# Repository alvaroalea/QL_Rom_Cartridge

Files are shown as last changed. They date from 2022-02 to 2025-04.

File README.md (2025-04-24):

# QL_Rom_Cartridge
Schematic, PCB and other stuff to make ROM Cartridge for use with Sinclair QL Computer

(C) 2022 Alvaro Alea Fdz.

License under: CERN Open Hardware Licence Version 2 - Strongly Reciprocal

https://ohwr.org/cern_ohl_s_v2.txt

Remenber that when using my jerber files with JLCPCB you shall mark the option to specify the Order Number (no cost) to avoid the text JLCJLCJLCJLC in the skilscreen.
My image

## Folder: Original
This folder contain the schematic of the original Sinclair cartridge as far as i can get from pictures from internet.

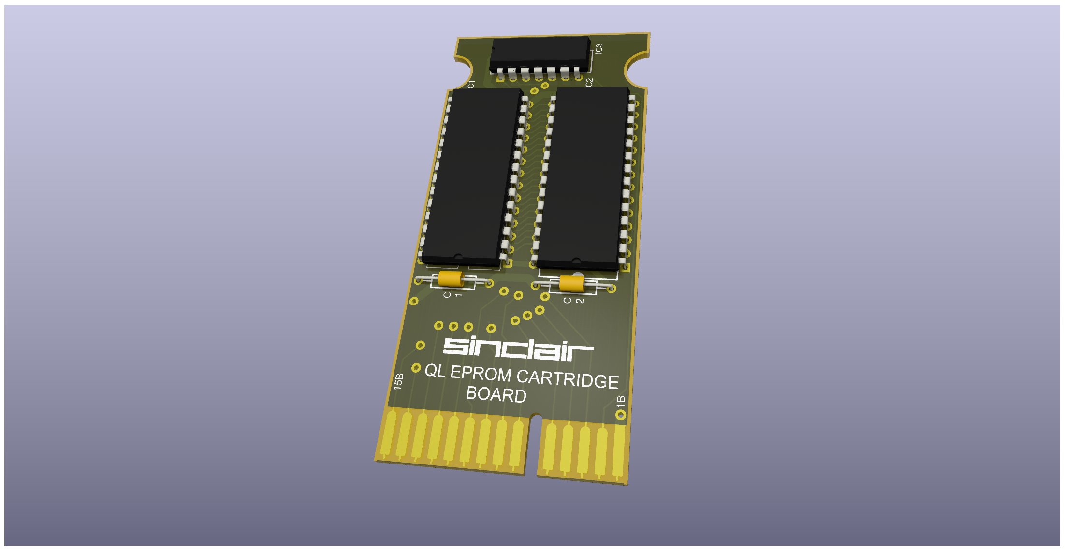
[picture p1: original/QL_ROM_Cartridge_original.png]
 

It also contains 3D pieces to do vacum form of the case

STATUS
- Schematic - Working, tested and match the original, Thank You Chr$.
- Case - Design, Non tested

## Folder: Short

### NOT TESTED, SHOULD WORK
This version need a 16Kb eprom, and is intended as a replacement of Toolkit II cartridge an others.
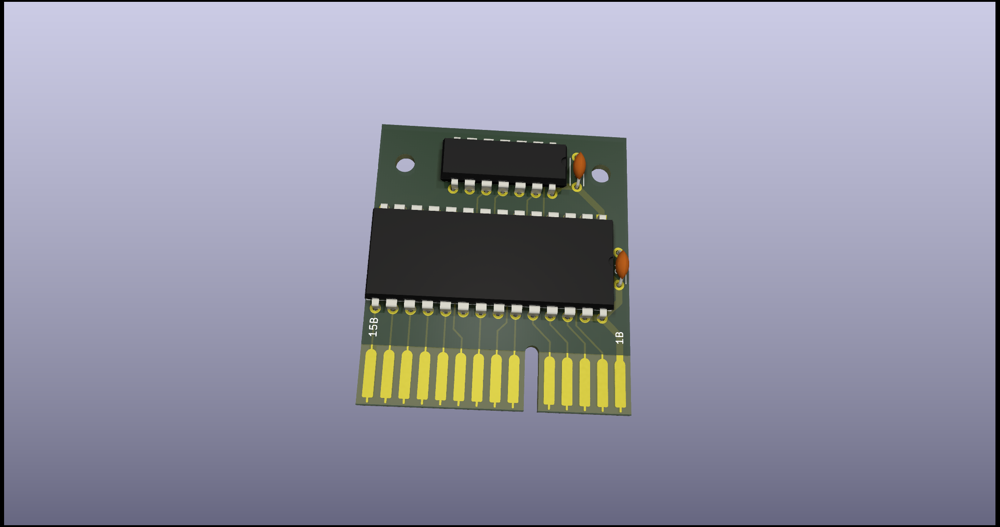
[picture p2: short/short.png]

## Folder: full_rom

### NOT TESTED, NO IDEA IF WORK
This version need a 64Kb eprom, and is intended to replace the internal ROM of the QL.

Is very important to remove the 2 ROM chips from the QL before use.

Be aware that this lock the rom cartridge, and the QL will not work without it.
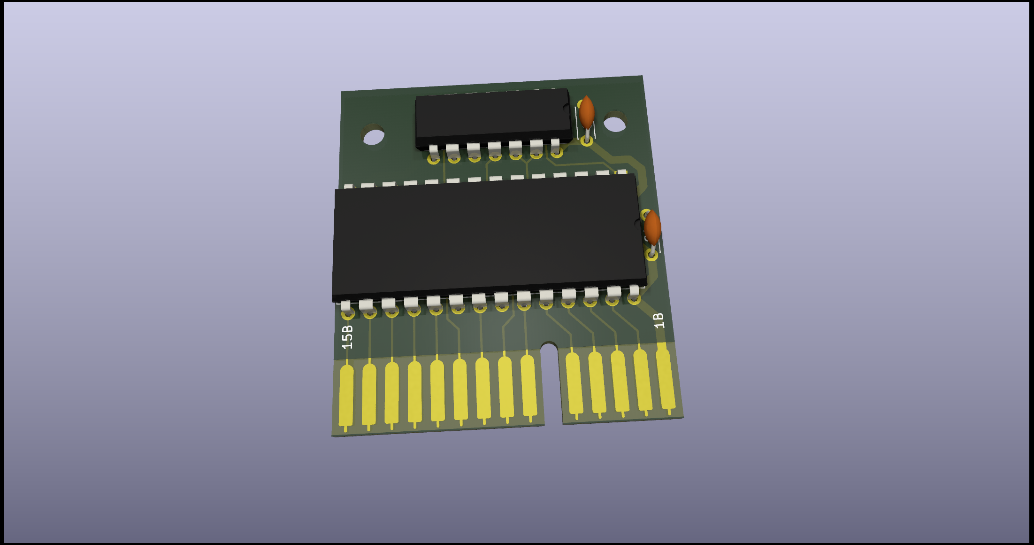
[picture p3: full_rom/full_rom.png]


## Folder: 8full_rom

### NOT TESTED, NO IDEA IF WORK
The 8full_rom is a version of full_rom with 3 switch to allow 8 diferent version of the ROM of the QL.

Is very important to remove the 2 ROM chips from the QL before use.

Be aware that this lock the rom cartridge, and the QL will not work without it.
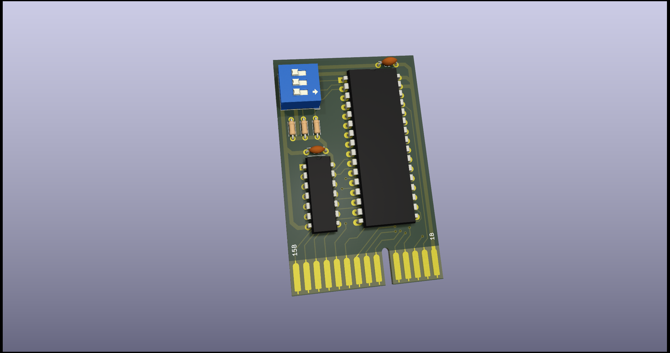
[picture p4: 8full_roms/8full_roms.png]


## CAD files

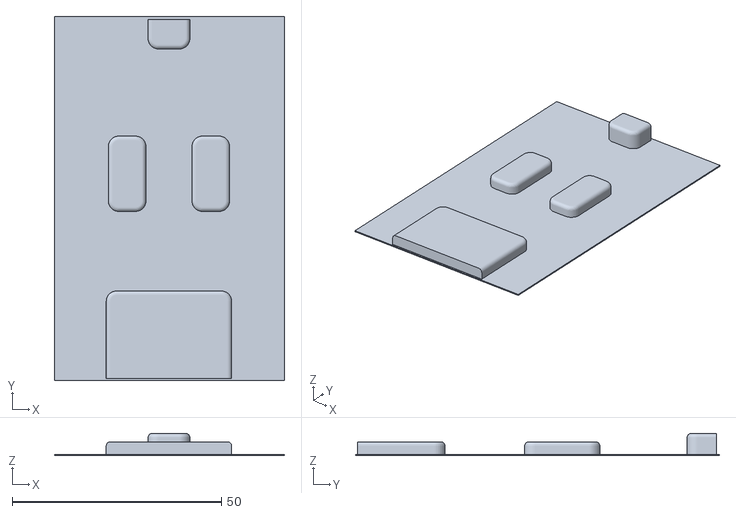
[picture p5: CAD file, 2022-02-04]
original/cartridge-Fusion001.stl
55.0 x 87.0 x 5.30

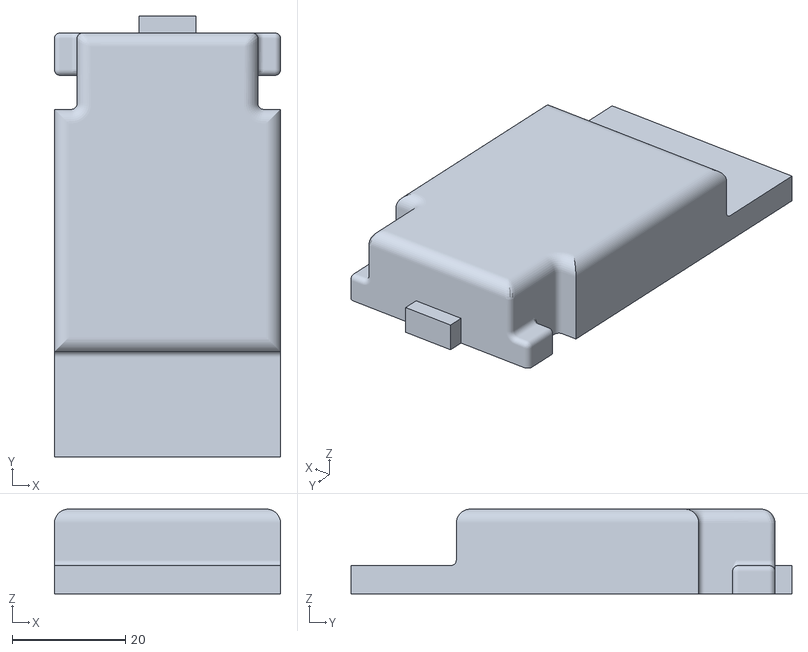
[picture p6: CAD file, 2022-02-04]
original/cartridge-Fillet001.stl
40.0 x 78.0 x 15.0

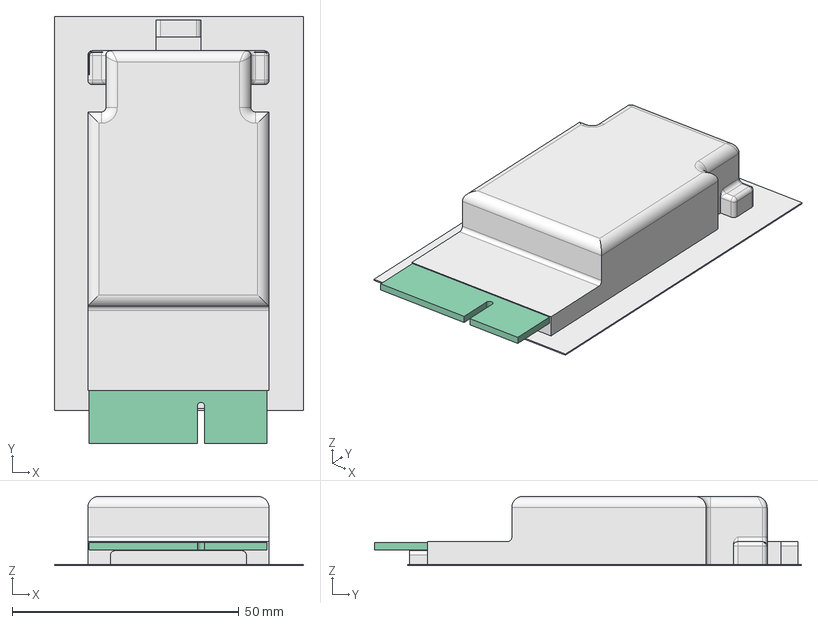
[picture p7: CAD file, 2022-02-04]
original/cartridge.FCStd
55.0 x 94.2 x 15.3 mm
Pcb_9943

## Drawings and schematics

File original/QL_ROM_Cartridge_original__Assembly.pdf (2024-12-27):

# 18,03 mm 8,89 mm

# 38,61 mm 34,04 mm ⁵,08 mm

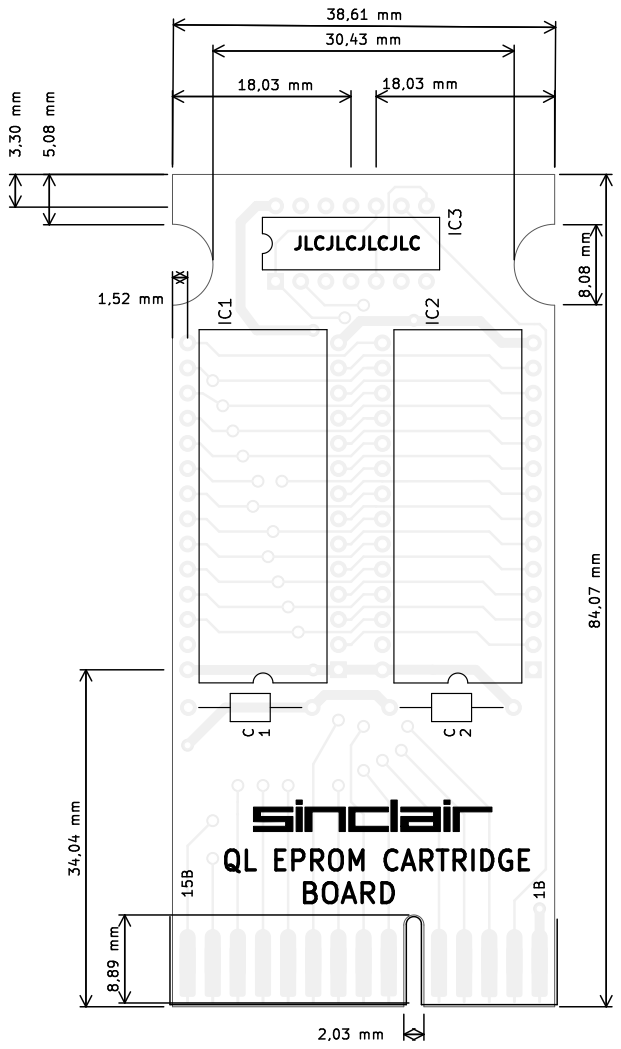
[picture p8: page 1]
D Date: 2022-02-04 KiCad; E.D.A. 8.0.6 Size: A4; Rev: 0; File: QL_ROM_Cartridge_original.kicad_pcb Sheet: Black; And; White; TOP; (c) 2022 Alvaro Alea; Fdz.; IC2 should; https://ohwr.org/cern_ohl_s_v2.txt CERN; Open; Hardware; Licence Version 2 - Strongly; Reciprocal Board2Pdf:; Black; TOP -; Page; JLCJLCJLCJLC BOARD; EPROM; CARTRIDGE

Id: 1/1 Title: 16Kb ROM Cartridge for Sinclair QL

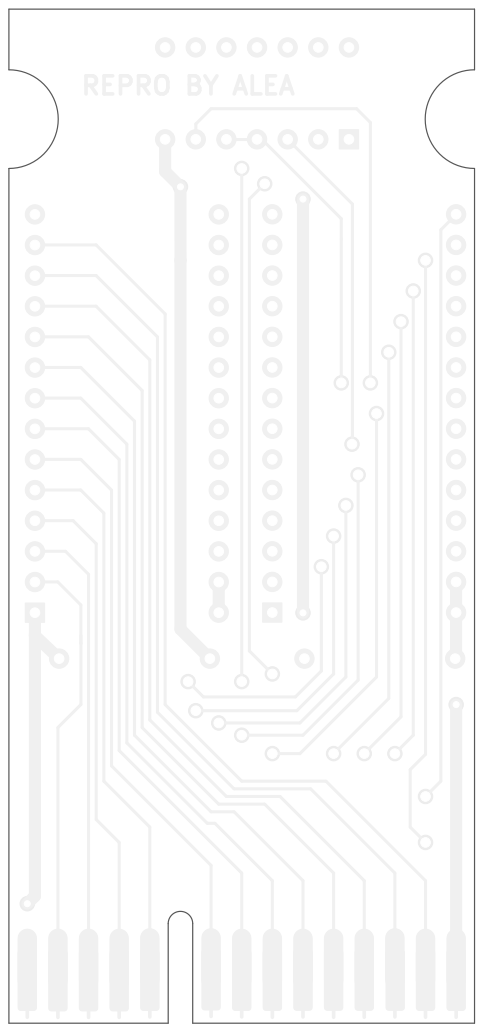
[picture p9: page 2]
REPRO; BY ALEA; D Date: 2022-02-04 KiCad; E.D.A. 8.0.6 Size: A4; Rev: 0; File: QL_ROM_Cartridge_original.kicad_pcb Sheet: Black; And; White; BOT; (c) 2022 Alvaro Alea; Fdz.; IC2 should; https://ohwr.org/cern_ohl_s_v2.txt CERN; Open; Hardware; Licence Version 2 - Strongly; Reciprocal Board2Pdf:; Black; BOT -; Page 2/2

Id: 1/1 Title: 16Kb ROM Cartridge for Sinclair QL

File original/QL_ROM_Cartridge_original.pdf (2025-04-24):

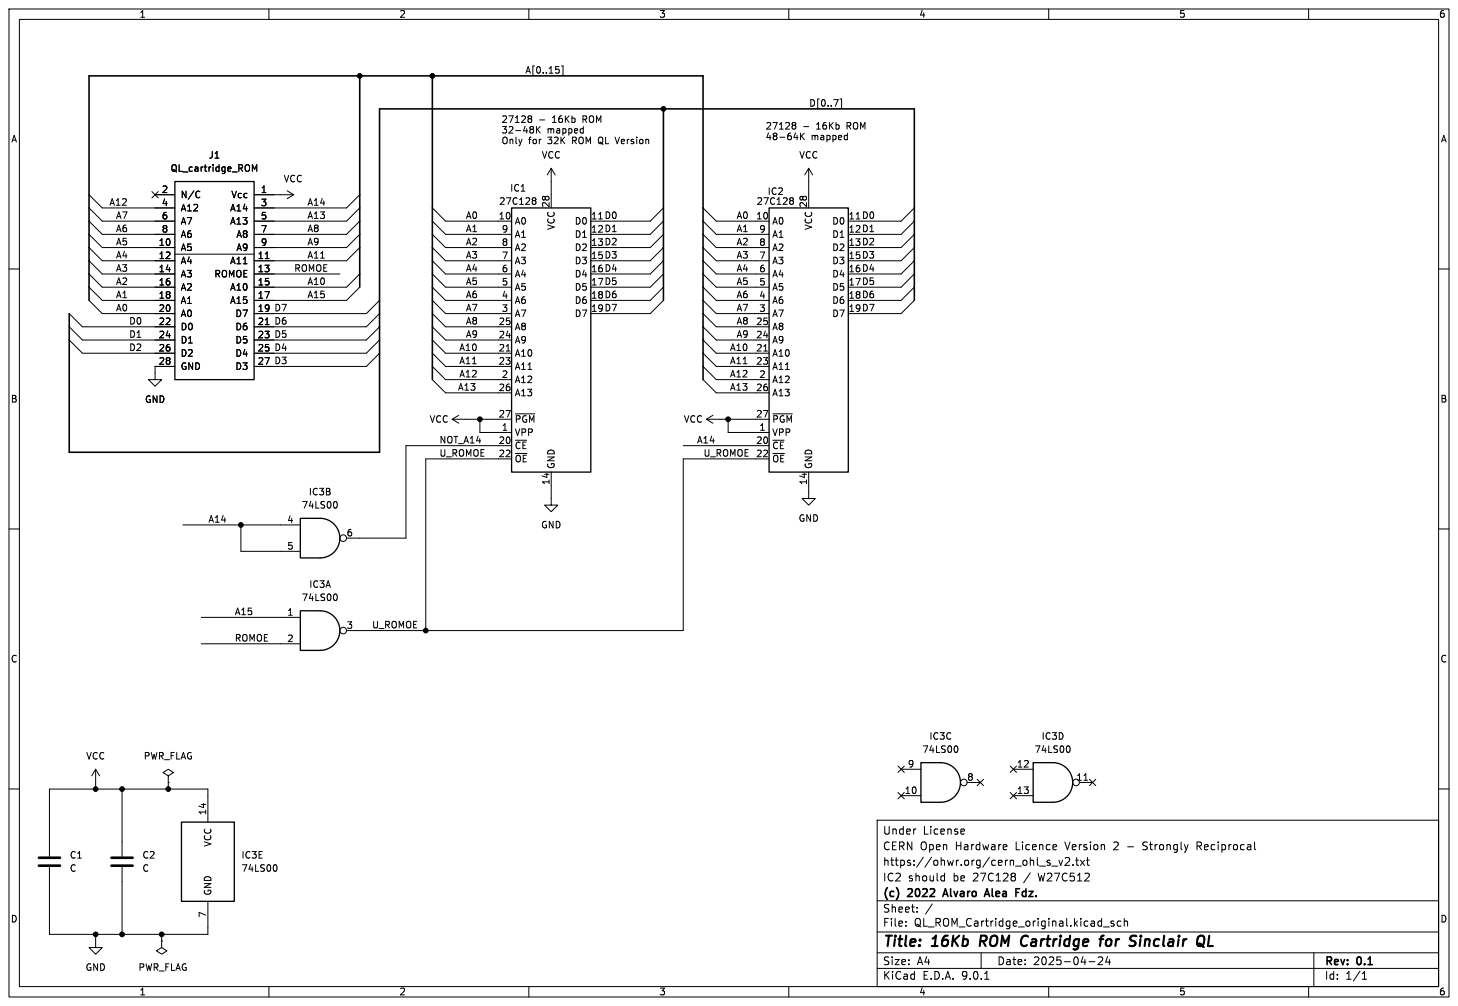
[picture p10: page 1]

Only for 32K ROM QL Version GND
J1 QL_cartridge_ROM

Id: 1/1 Title: 16Kb ROM Cartridge for Sinclair QL

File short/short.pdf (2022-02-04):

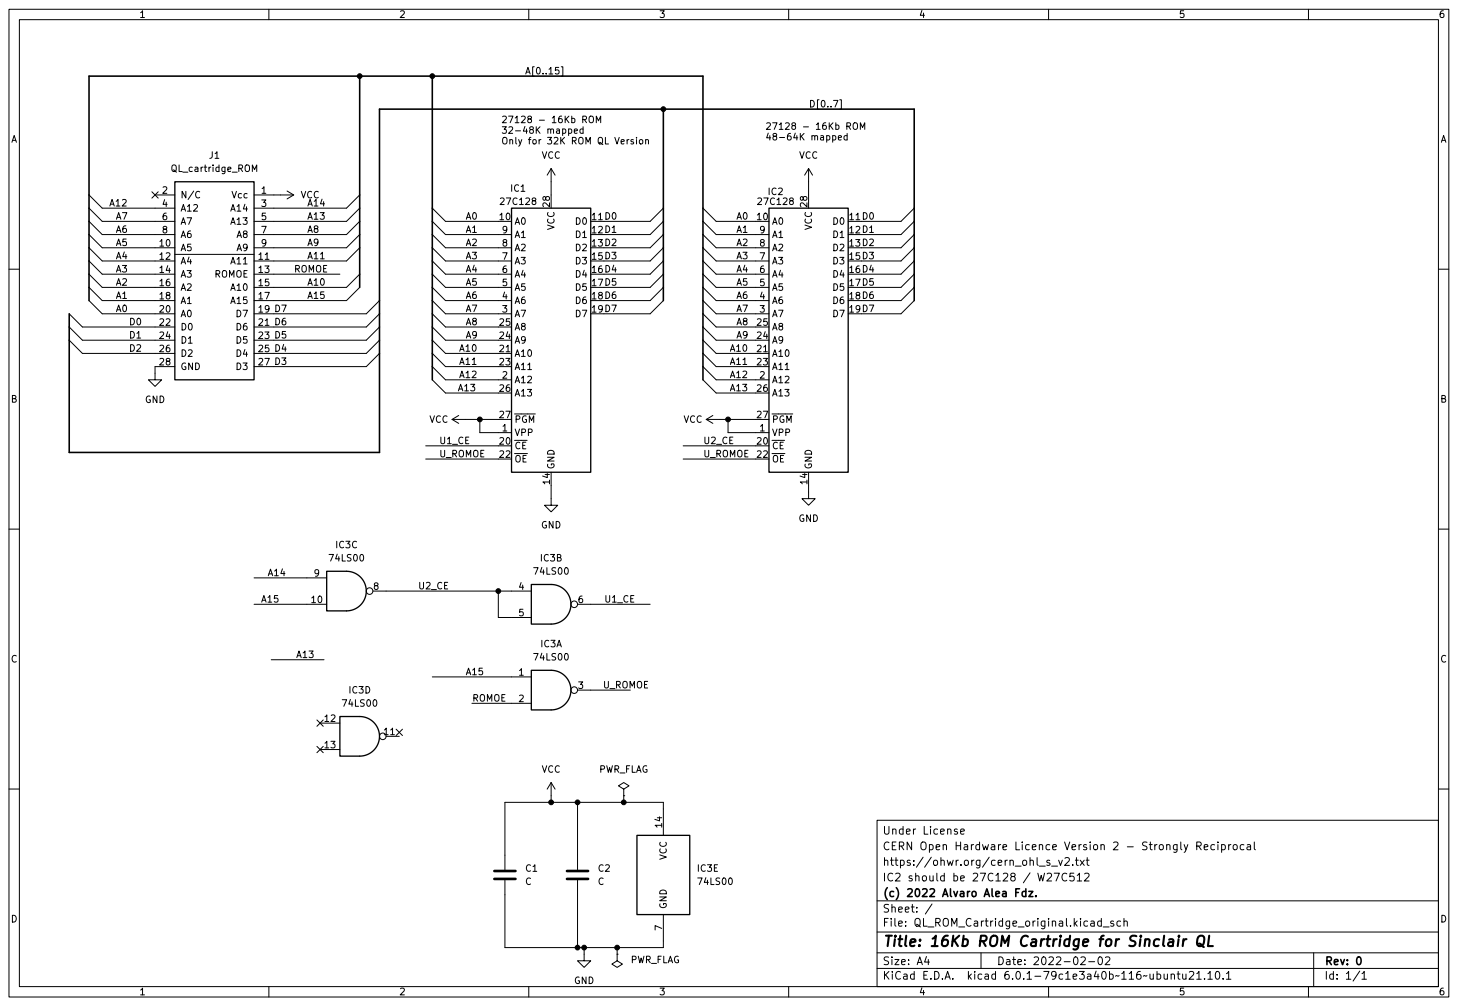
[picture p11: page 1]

27128 - 16Kb ROM
32-48K mapped
Only for 32K ROM QL Version

CERN Open Hardware Licence Version 2 - Strongly Reciprocal Under License PWR_FLAG

https://ohwr.org/cern_ohl_s_v2.txt
IC2 should be 27C128 / W27C512
File: QL_ROM_Cartridge_original.kicad_sch Sheet: / (c) 2022 Alvaro Alea Fdz.

Id: 1/1 Title: 16Kb ROM Cartridge for Sinclair QL

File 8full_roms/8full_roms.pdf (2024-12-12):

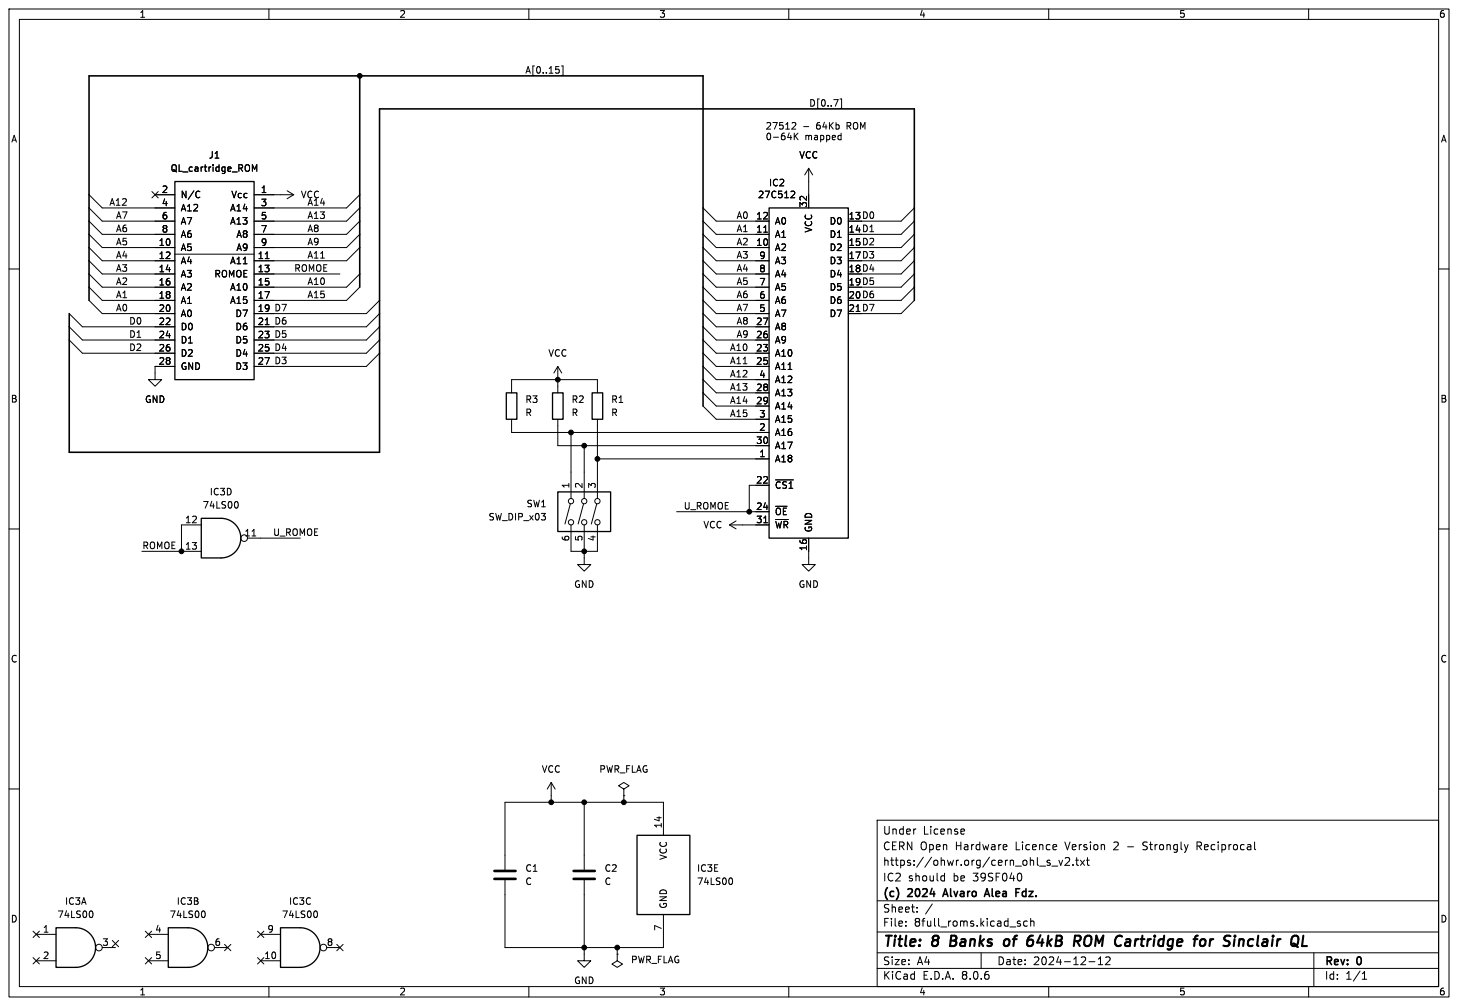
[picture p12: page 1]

Id: 1/1 Title: 8 Banks of 64kB ROM Cartridge for Sinclair QL

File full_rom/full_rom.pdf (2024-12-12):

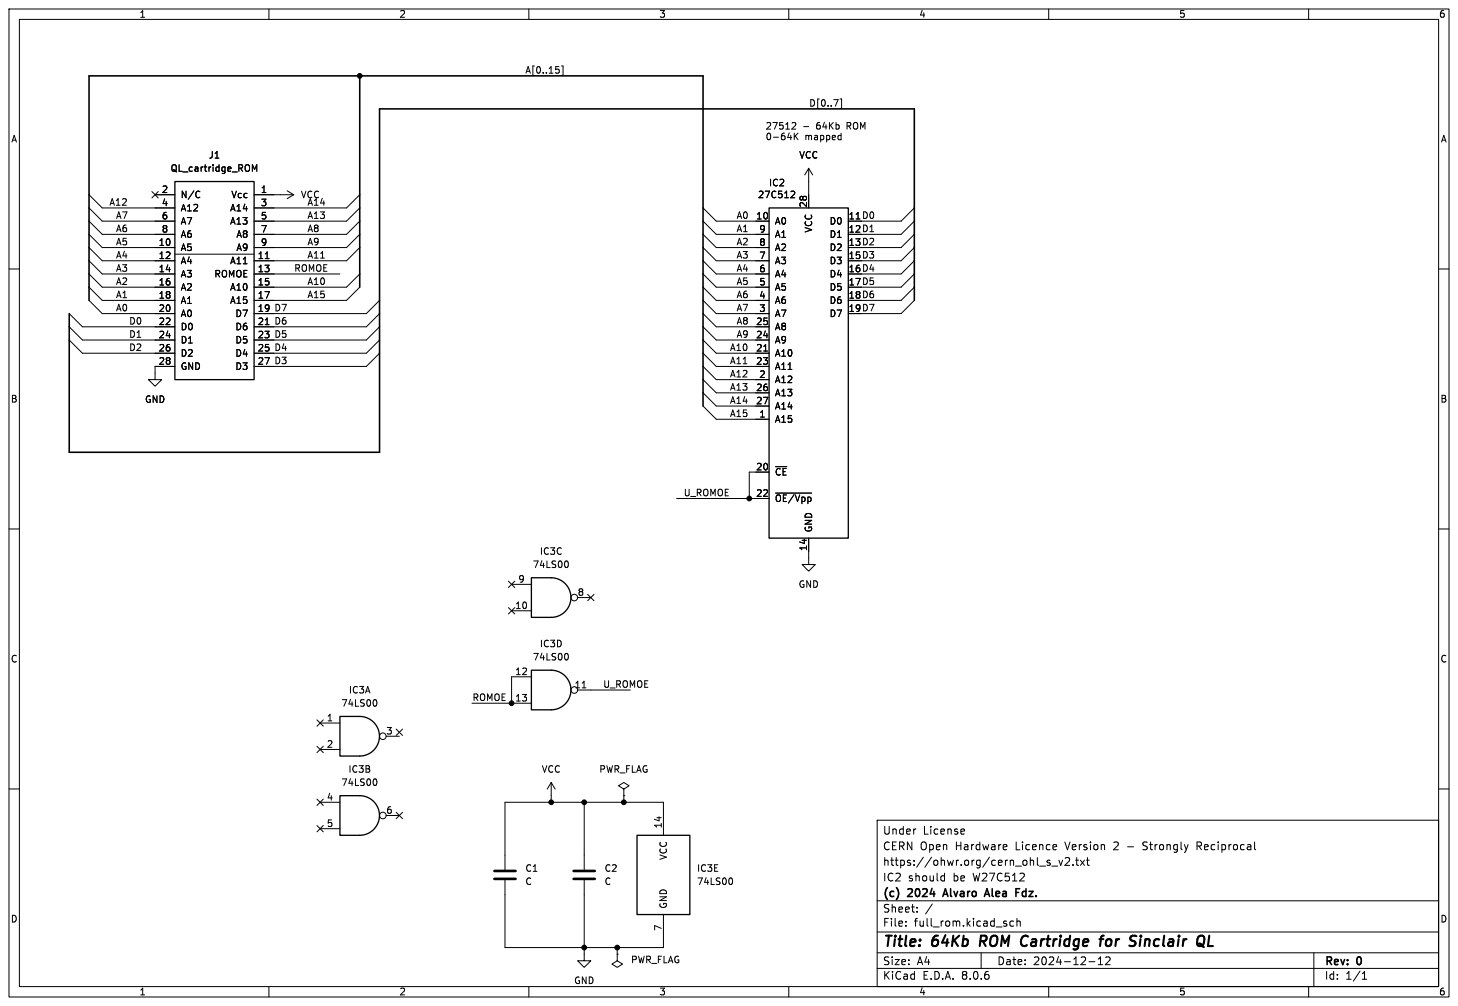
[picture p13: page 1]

Id: 1/1 Title: 64Kb ROM Cartridge for Sinclair QL

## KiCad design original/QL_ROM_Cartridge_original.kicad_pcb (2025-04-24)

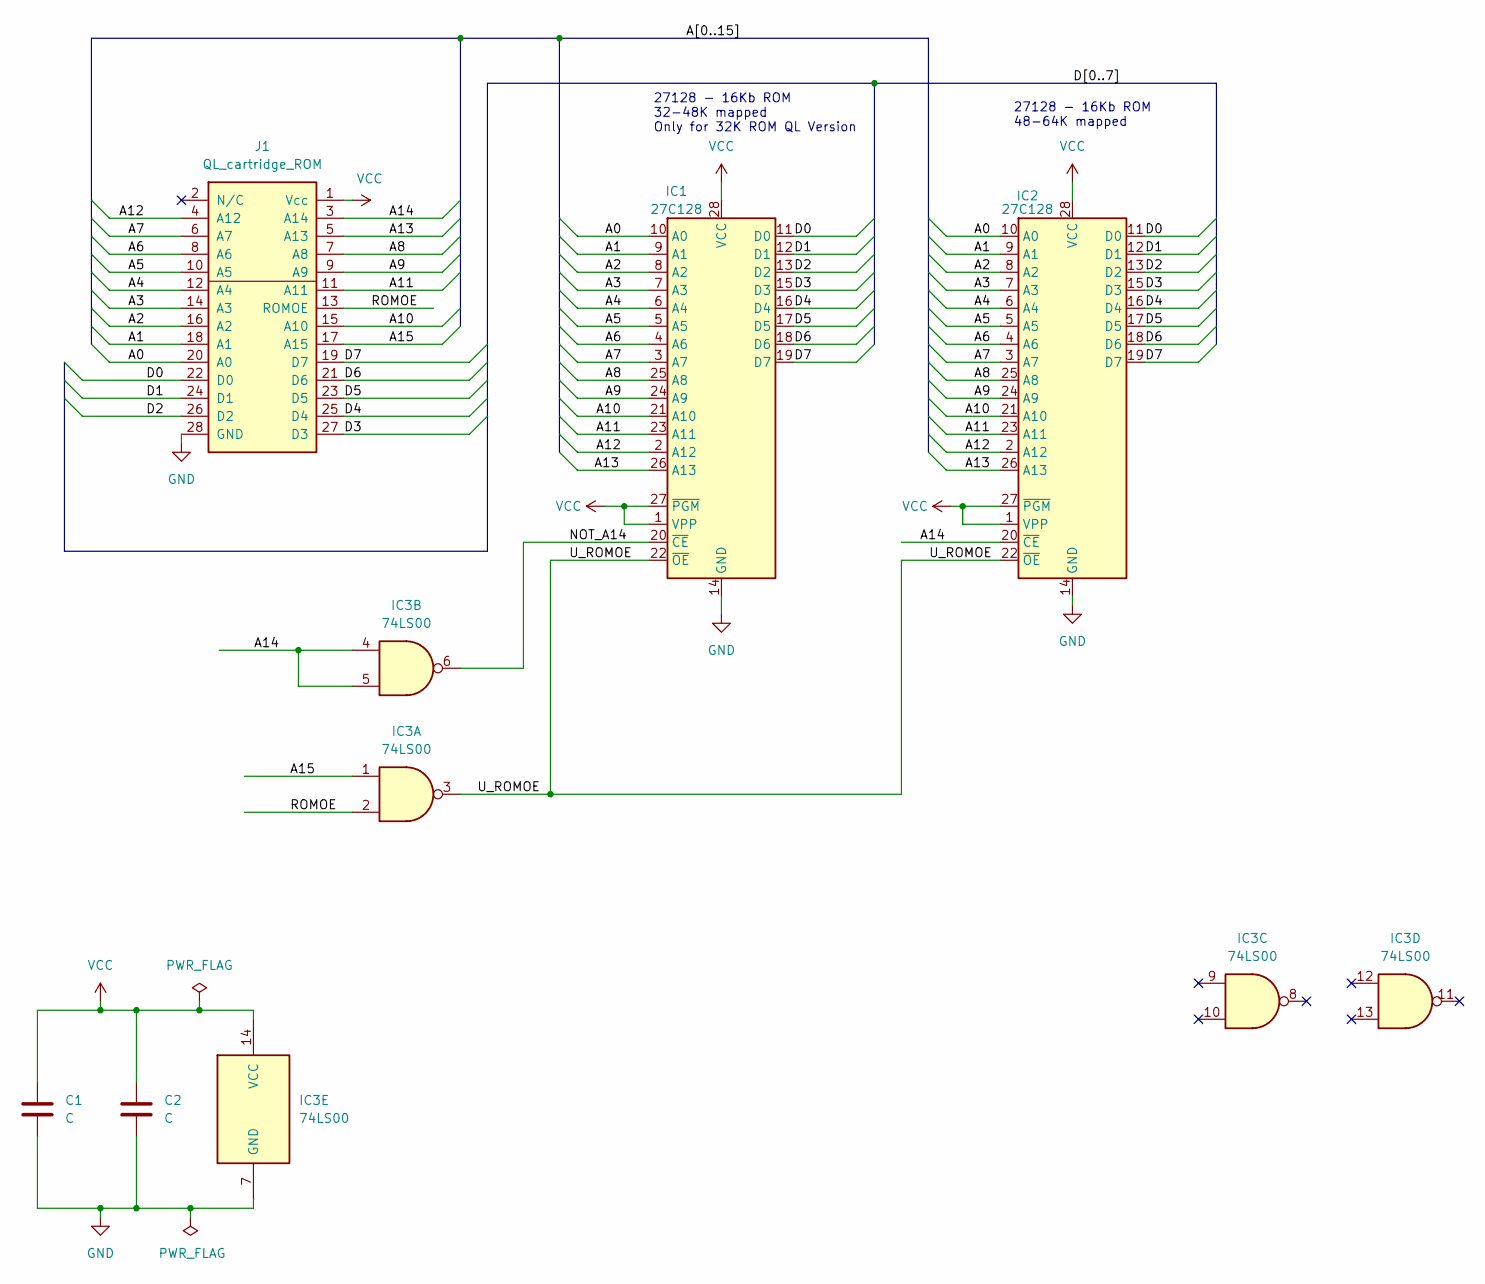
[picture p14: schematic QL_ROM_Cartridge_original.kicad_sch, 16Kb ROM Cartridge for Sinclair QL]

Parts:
C1: C; C_Axial_L3.8mm_D2.6mm_P12.50mm_Horizontal_Sinclair_Cartridge
C2: C; C_Axial_L3.8mm_D2.6mm_P12.50mm_Horizontal
IC1: 27C128; DIP-28_W15.24mm_sinclair_cartridge
IC2: 27C128; DIP-28_W15.24mm
IC3: 74LS00; DIP-14_W7.62mm
J1: QL_cartridge_ROM; CART_QL_EDGE

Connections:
/A0: IC1.10 (A0), IC2.10 (A0), J1.20 (A0)
/A1: IC1.9 (A1), IC2.9 (A1), J1.18 (A1)
/A2: IC1.8 (A2), IC2.8 (A2), J1.16 (A2)
/A3: IC1.7 (A3), IC2.7 (A3), J1.14 (A3)
/A4: IC1.6 (A4), IC2.6 (A4), J1.12 (A4)
/A5: IC1.5 (A5), IC2.5 (A5), J1.10 (A5)
/A6: IC1.4 (A6), IC2.4 (A6), J1.8 (A6)
/A7: IC1.3 (A7), IC2.3 (A7), J1.6 (A7)
/A8: IC1.25 (A8), IC2.25 (A8), J1.7 (A8)
/A9: IC1.24 (A9), IC2.24 (A9), J1.9 (A9)
/A10: IC1.21 (A10), IC2.21 (A10), J1.15 (A10)
/A11: IC1.23 (A11), IC2.23 (A11), J1.11 (A11)
/A12: IC1.2 (A12), IC2.2 (A12), J1.4 (A12)
/A13: IC1.26 (A13), IC2.26 (A13), J1.5 (A13)
/A14: IC2.20 (~CE), IC3.4, IC3.5, J1.3 (A14)
/A15: IC3.1, J1.17 (A15)
/D0: IC1.11 (D0), IC2.11 (D0), J1.22 (D0)
/D1: IC1.12 (D1), IC2.12 (D1), J1.24 (D1)
/D2: IC1.13 (D2), IC2.13 (D2), J1.26 (D2)
/D3: IC1.15 (D3), IC2.15 (D3), J1.27 (D3)
/D4: IC1.16 (D4), IC2.16 (D4), J1.25 (D4)
/D5: IC1.17 (D5), IC2.17 (D5), J1.23 (D5)
/D6: IC1.18 (D6), IC2.18 (D6), J1.21 (D6)
/D7: IC1.19 (D7), IC2.19 (D7), J1.19 (D7)
/NOT_A14: IC1.20 (~CE), IC3.6
/ROMOE: IC3.2, J1.13 (ROMOE)
/U_ROMOE: IC1.22 (~OE), IC2.22 (~OE), IC3.3
GND: C1.2, C2.2, IC1.14 (GND), IC2.14 (GND), IC3.7 (GND), J1.28 (GND)
VCC: C1.1, C2.1, IC1.1 (VPP), IC1.27 (~PGM), IC1.28 (VCC), IC2.1 (VPP), IC2.27 (~PGM), IC2.28 (VCC), IC3.14 (VCC), J1.1 (Vcc)

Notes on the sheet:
27128 - 16Kb ROM 32-48K mapped Only for 32K ROM QL Version
27128 - 16Kb ROM 48-64K mapped

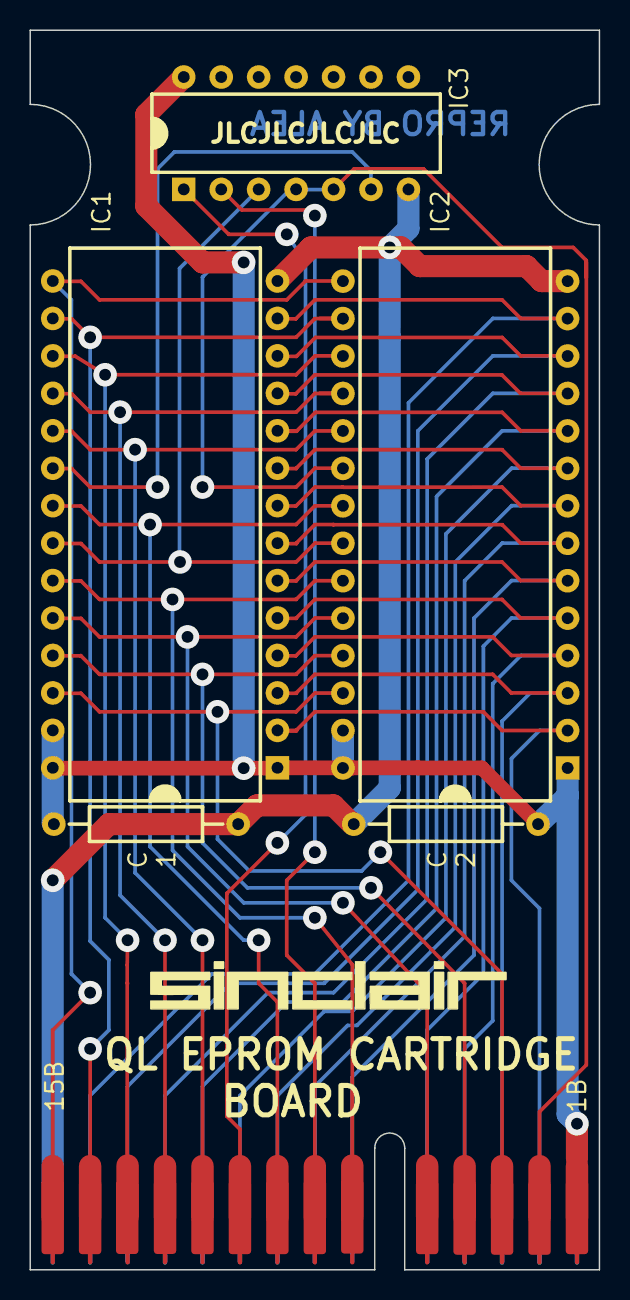
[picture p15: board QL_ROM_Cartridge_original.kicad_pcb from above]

Board: 2 copper layers, 38.6 x 84.1 mm, 6 parts (0 on the bottom side), 29 nets.

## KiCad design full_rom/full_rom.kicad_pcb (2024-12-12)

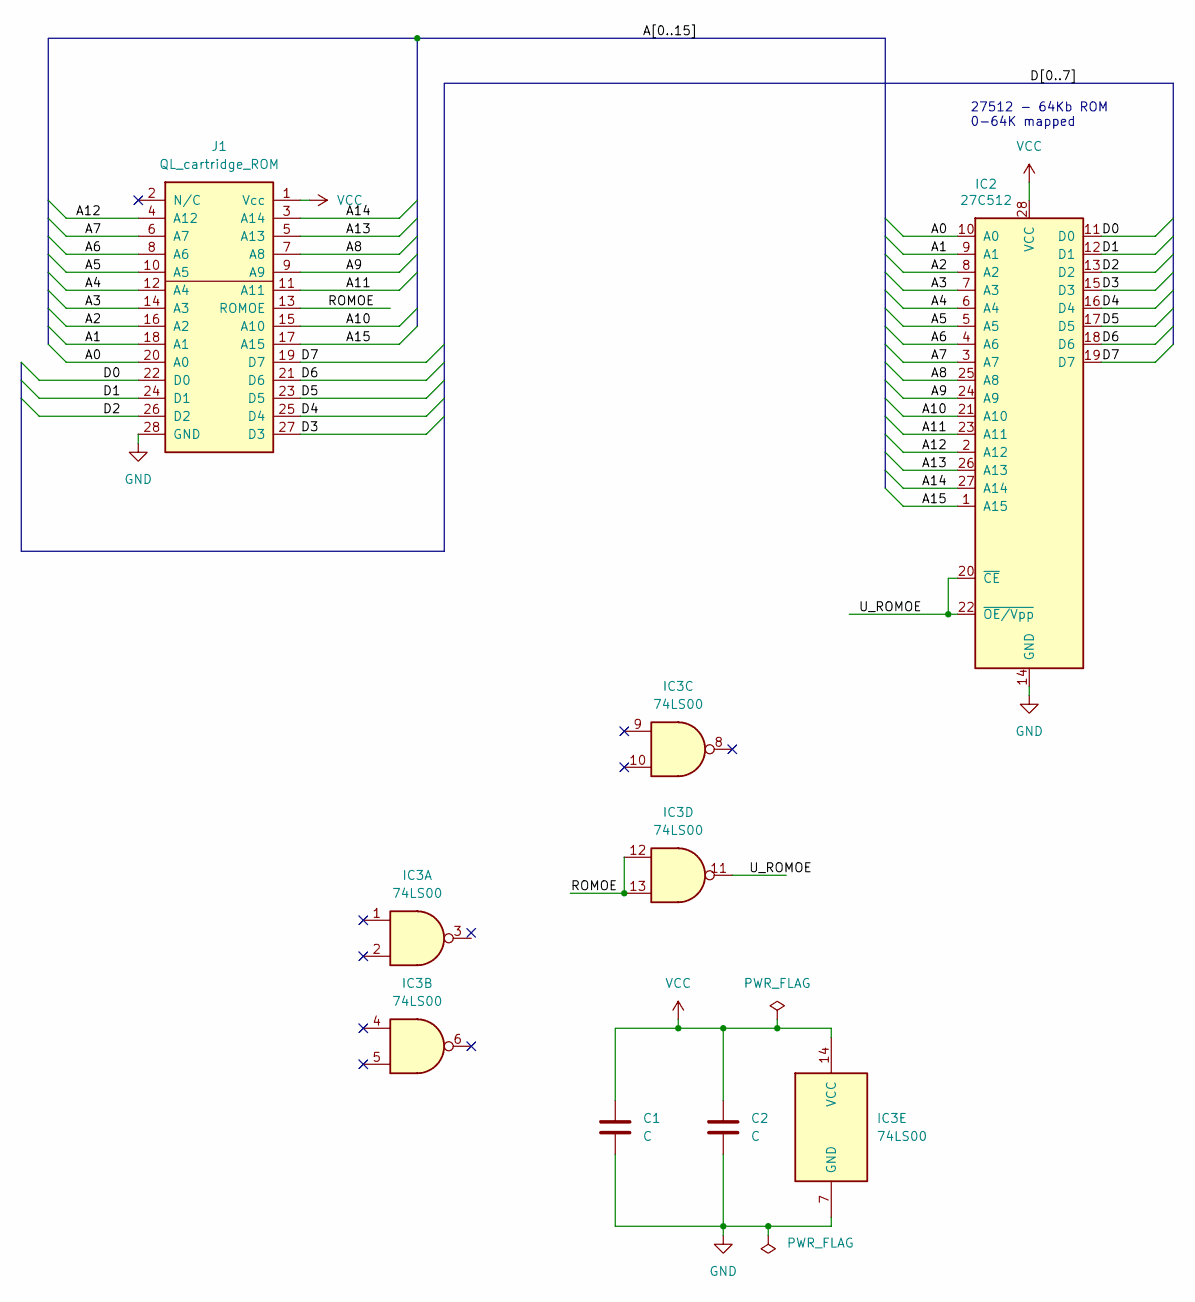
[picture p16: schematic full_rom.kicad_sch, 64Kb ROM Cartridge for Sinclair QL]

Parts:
C1, C2: C; C_Disc_D4.3mm_W1.9mm_P5.00mm
IC2: 27C512; DIP-28_W15.24mm
IC3: 74LS00; DIP-14_W7.62mm
J1: QL_cartridge_ROM; CART_QL_EDGE

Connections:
/A0: IC2.10 (A0), J1.20 (A0)
/A1: IC2.9 (A1), J1.18 (A1)
/A2: IC2.8 (A2), J1.16 (A2)
/A3: IC2.7 (A3), J1.14 (A3)
/A4: IC2.6 (A4), J1.12 (A4)
/A5: IC2.5 (A5), J1.10 (A5)
/A6: IC2.4 (A6), J1.8 (A6)
/A7: IC2.3 (A7), J1.6 (A7)
/A8: IC2.25 (A8), J1.7 (A8)
/A9: IC2.24 (A9), J1.9 (A9)
/A10: IC2.21 (A10), J1.15 (A10)
/A11: IC2.23 (A11), J1.11 (A11)
/A12: IC2.2 (A12), J1.4 (A12)
/A13: IC2.26 (A13), J1.5 (A13)
/A14: IC2.27 (A14), J1.3 (A14)
/A15: IC2.1 (A15), J1.17 (A15)
/D0: IC2.11 (D0), J1.22 (D0)
/D1: IC2.12 (D1), J1.24 (D1)
/D2: IC2.13 (D2), J1.26 (D2)
/D3: IC2.15 (D3), J1.27 (D3)
/D4: IC2.16 (D4), J1.25 (D4)
/D5: IC2.17 (D5), J1.23 (D5)
/D6: IC2.18 (D6), J1.21 (D6)
/D7: IC2.19 (D7), J1.19 (D7)
/ROMOE: IC3.12, IC3.13, J1.13 (ROMOE)
/U_ROMOE: IC2.20 (~CE), IC2.22 (~OE/Vpp), IC3.11
GND: C1.2, C2.2, IC2.14 (GND), IC3.7 (GND), J1.28 (GND)
VCC: C1.1, C2.1, IC2.28 (VCC), IC3.14 (VCC), J1.1 (Vcc)

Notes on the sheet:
27512 - 64Kb ROM 0-64K mapped

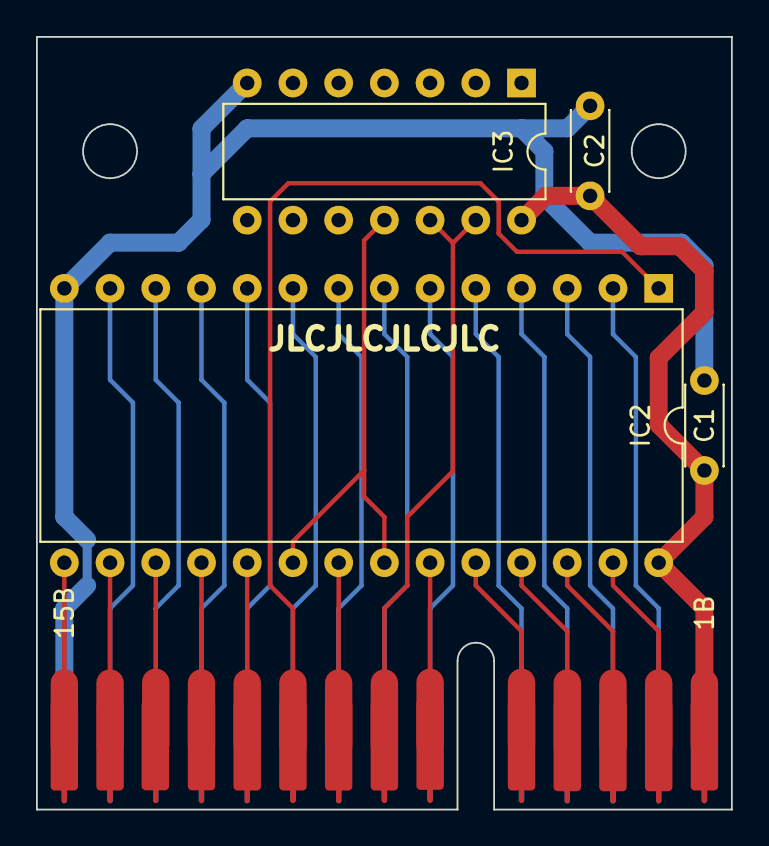
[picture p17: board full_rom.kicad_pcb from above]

Board: 2 copper layers, 38.6 x 42.9 mm, 5 parts (0 on the bottom side), 28 nets.

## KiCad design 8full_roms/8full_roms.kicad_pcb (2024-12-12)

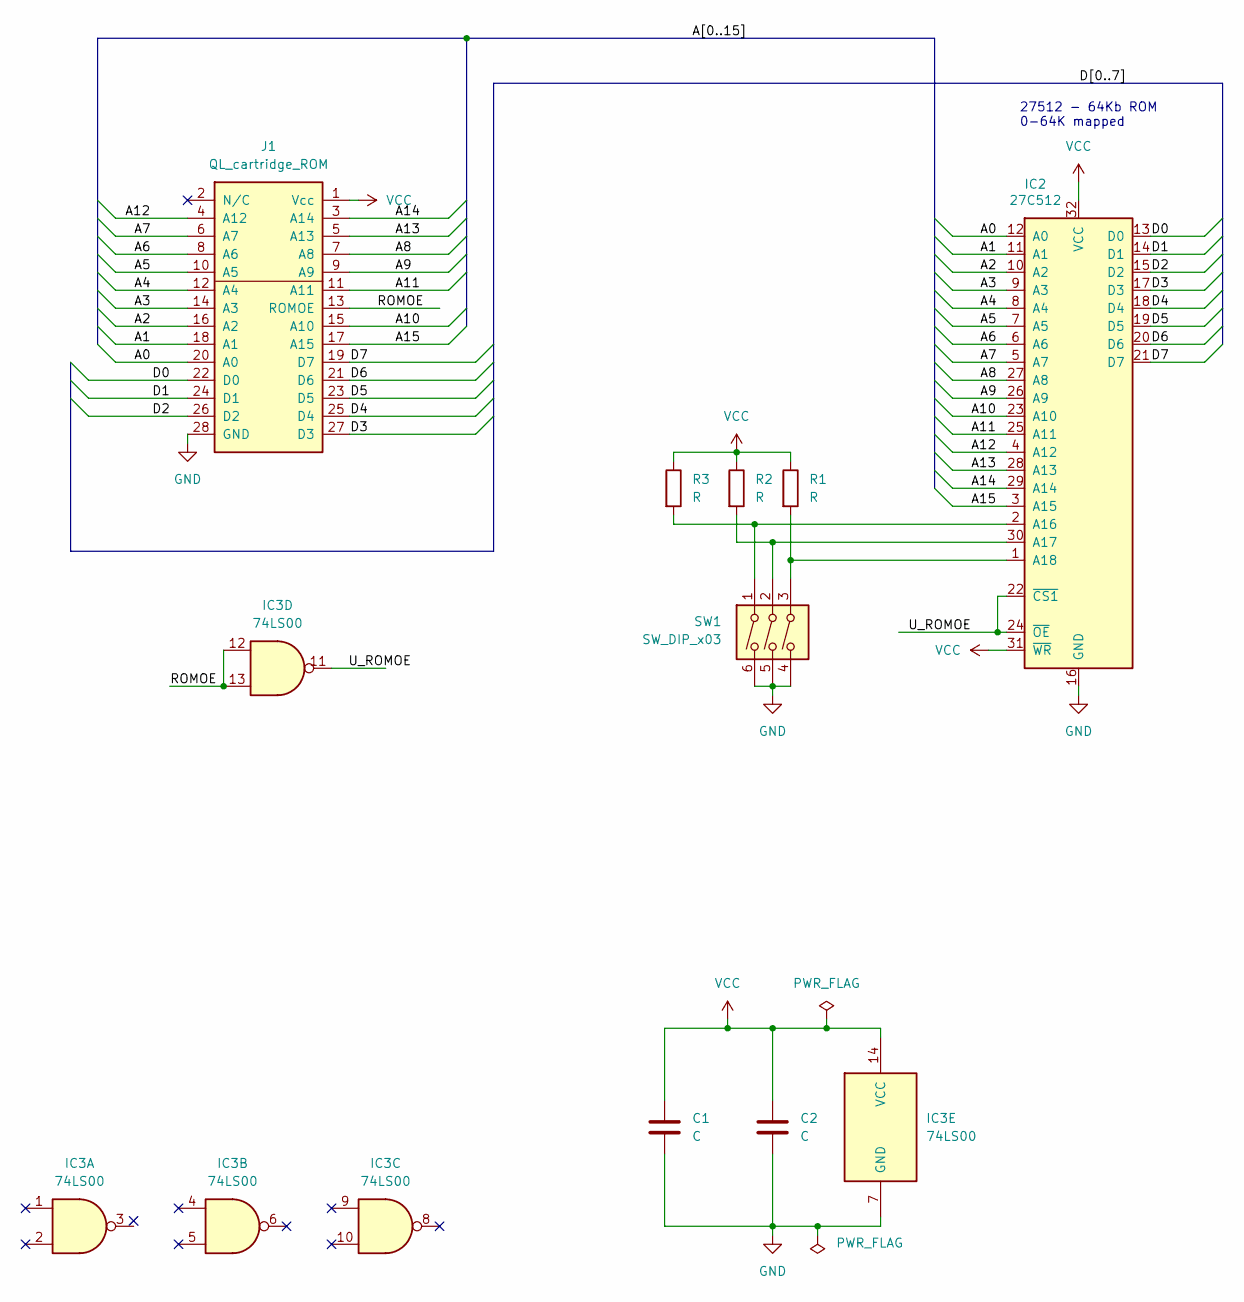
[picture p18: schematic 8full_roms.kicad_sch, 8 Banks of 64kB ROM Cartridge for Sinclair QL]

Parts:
C1, C2: C; C_Disc_D4.3mm_W1.9mm_P5.00mm
IC2: 27C512; DIP-32_W15.24mm_LongPads
IC3: 74LS00; DIP-14_W7.62mm
J1: QL_cartridge_ROM; CART_QL_EDGE
R1, R2, R3: R; R_Axial_DIN0204_L3.6mm_D1.6mm_P5.08mm_Horizontal
SW1: SW_DIP_x03; SW_DIP_SPSTx03_Slide_9.78x9.8mm_W7.62mm_P2.54mm

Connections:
/A0: IC2.12 (A0), J1.20 (A0)
/A1: IC2.11 (A1), J1.18 (A1)
/A2: IC2.10 (A2), J1.16 (A2)
/A3: IC2.9 (A3), J1.14 (A3)
/A4: IC2.8 (A4), J1.12 (A4)
/A5: IC2.7 (A5), J1.10 (A5)
/A6: IC2.6 (A6), J1.8 (A6)
/A7: IC2.5 (A7), J1.6 (A7)
/A8: IC2.27 (A8), J1.7 (A8)
/A9: IC2.26 (A9), J1.9 (A9)
/A10: IC2.23 (A10), J1.15 (A10)
/A11: IC2.25 (A11), J1.11 (A11)
/A12: IC2.4 (A12), J1.4 (A12)
/A13: IC2.28 (A13), J1.5 (A13)
/A14: IC2.29 (A14), J1.3 (A14)
/A15: IC2.3 (A15), J1.17 (A15)
/D0: IC2.13 (D0), J1.22 (D0)
/D1: IC2.14 (D1), J1.24 (D1)
/D2: IC2.15 (D2), J1.26 (D2)
/D3: IC2.17 (D3), J1.27 (D3)
/D4: IC2.18 (D4), J1.25 (D4)
/D5: IC2.19 (D5), J1.23 (D5)
/D6: IC2.20 (D6), J1.21 (D6)
/D7: IC2.21 (D7), J1.19 (D7)
/ROMOE: IC3.12, IC3.13, J1.13 (ROMOE)
/U_ROMOE: IC2.22 (~CS1), IC2.24 (~OE), IC3.11
GND: C1.2, C2.2, IC2.16 (GND), IC3.7 (GND), J1.28 (GND), SW1.4, SW1.5, SW1.6
unnamed: IC2.2 (A16), R3.2, SW1.1
unnamed: IC2.30 (A17), R2.2, SW1.2
unnamed: IC2.1 (A18), R1.2, SW1.3
VCC: C1.1, C2.1, IC2.31 (~WR), IC2.32 (VCC), IC3.14 (VCC), J1.1 (Vcc), R1.1, R2.1, R3.1

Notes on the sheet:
27512 - 64Kb ROM 0-64K mapped

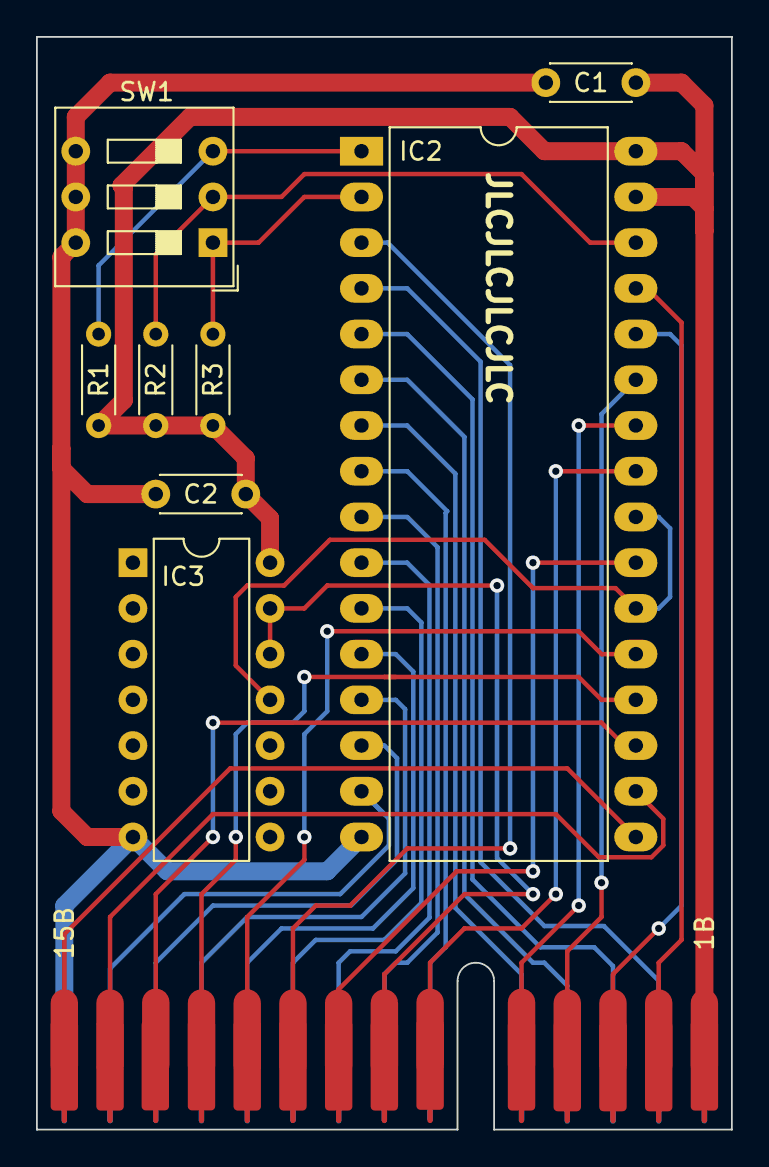
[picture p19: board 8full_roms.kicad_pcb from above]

Board: 2 copper layers, 38.6 x 60.7 mm, 9 parts (0 on the bottom side), 31 nets.

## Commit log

2022-02-04 text updated
    [QL_ROM_Cartridge_original.kicad_pcb, QL_ROM_Cartridge_original.kicad_sch]
2022-07-15 Update size after feedback
    [QL_ROM_Cartridge_original.kicad_pcb]
2024-12-12 new pcbs
    [8full_roms-B_Cu.gbr, 8full_roms-B_Mask.gbr, 8full_roms-B_Paste.gbp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]
2025-04-24 Updated Original PCB
    [QL_ROM_Cartridge_original-B_Cu.gbr, QL_ROM_Cartridge_original-B_Mask.gbr, QL_ROM_Cartridge_original-B_Paste.gbp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]
2025-08-04 fix gerber for 8 full roms

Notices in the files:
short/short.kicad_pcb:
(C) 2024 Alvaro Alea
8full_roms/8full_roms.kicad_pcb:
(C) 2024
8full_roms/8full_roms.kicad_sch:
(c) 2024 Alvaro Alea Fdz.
